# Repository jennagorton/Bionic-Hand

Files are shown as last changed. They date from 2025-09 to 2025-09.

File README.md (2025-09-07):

<h1 align="center">Bionic Hand</h1>
<p align="center">Jenna Gorton, July 2025</p>

<p align="center">
  workingTest
</p>
<p align="center">Opening and closing fist with button input</p>

About
==
In this project, I designed and built a bionic hand controlled by user input. I undertook this challenge to enhance my skills in CAD design, programming, and electronics. While only using my laptop, 3D printer, and Arduino, I was able to bring this idea to life. The primary goals were to achieve realistic hand motion and enable both independent and simultaneous control of individual fingers, while staying within a low budget.

<p align="center">
  workingTest
</p>

Design
==
The design incorporates compliant fingers, palm-integrated motors, a capacitive touch interface, and a cable-concealing stand.
- To introduce compliance in the fingers, I fabricated the joints using TPU, while the rest of the structure was printed in PLA. This material combination allowed the fingers to bend under applied force and return to their original position, providing the strength of a rigid finger with the flexibility of a compliant one.
- By integrating the servos within the palm, the hand functions independently without requiring an attached arm. This compact, self-contained design ensures compatibility with various arm attachments—whether used as a prosthetic or as a component of a larger robotic system.

Programming  
==

The bionic hand is controlled using an **Adafruit 16-Channel PWM Servo Driver** (PCA9685) and an Arduino. Each finger is assigned to a dedicated servo motor, which the driver addresses through I²C communication. The servos are configured with defined pulse-width ranges to open and close the fingers smoothly.  

### Key Features  
- **Finger Control**  
  The top row of capacitive touch sensors each corresponds to a specific finger. When touched, the associated servo toggles between open and closed positions, where the servo controls the closure, and the compliance pulls the finger open.

- **Predefined Gestures**  
  The second row of touch sensors allows for more complex motions:  
  - **Close Fist** – Sequentially closes all five fingers.  
  - **Open Hand** – Sequentially opens all five fingers.  
  - **Peace Sign** – Closes the thumb, ring, and pinky while opening the index and middle fingers.  

- **State Tracking**  
  Finger positions are tracked with global variables (`indexPos`, `thumbPos`, etc.) to prevent conflicting commands and allow toggling.  

- **Smooth Motion**  
  Servo positions are updated incrementally with small delays to create natural, fluid finger movements instead of abrupt snapping.  

### Example: Peace Sign Gesture  
Below is the function that creates a **peace sign** when the corresponding touch sensor is pressed:  

```cpp
if (c4r2 == 1) { // Peace sign gesture
  for (uint16_t pulselen = SERVOMAX, pulseopp = SERVOMIN; 
       pulselen > SERVOMIN && pulseopp < SERVOMAX; 
       pulselen--, pulseopp++) {
    // Closing thumb, ring, pinky
    if (thumbPos == 0) pwm.setPWM(THUMB, 0, pulselen);
    if (ringPos == 0)  pwm.setPWM(RING, 0, pulselen);
    if (pinkyPos == 0) pwm.setPWM(PINKY, 0, pulselen);

    // Opening index, middle
    if (middlePos == 1) pwm.setPWM(MIDDLE, 0, pulseopp);
    if (indexPos == 1)  pwm.setPWM(INDEX, 0, pulseopp);

    delay(3); // Smooth motion
  }
  indexPos = middlePos = 0; // Open
  ringPos = pinkyPos = thumbPos = 1; // Closed
}

```
Demo
==
The fingers can be configured to create any hand gesture 

| <div align="center">GIF 1<br></div> | <div align="center">GIF 2<br></div> |
|---|---|
| <div align="center">GIF 3<br></div> | <div align="center">GIF 4<br></div> |

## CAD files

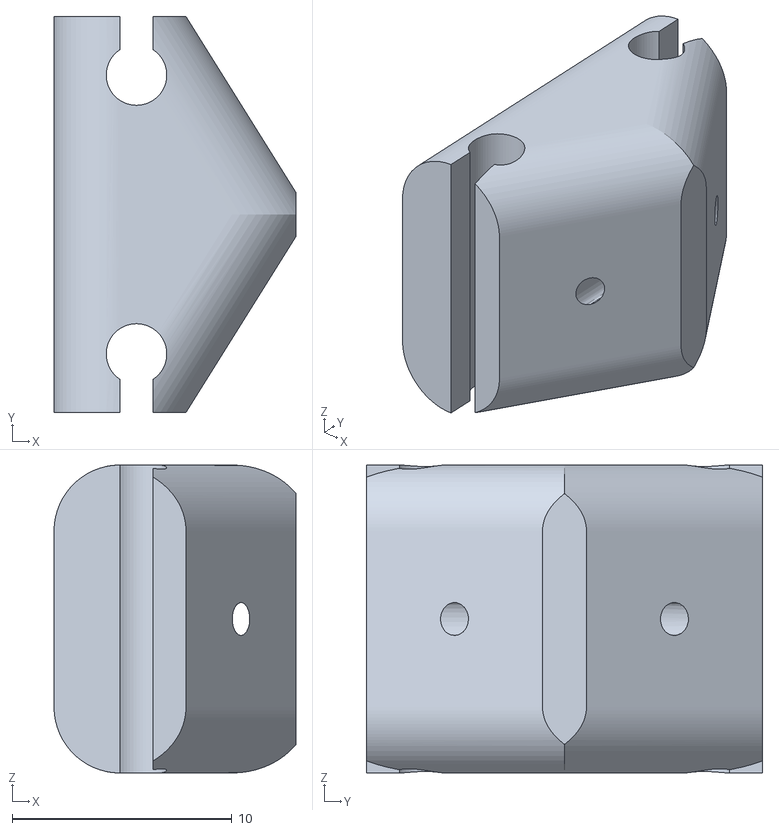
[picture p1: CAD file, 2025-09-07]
STL Files/Assembly 2 - P Middle.stl
11.0 x 18.0 x 14.0

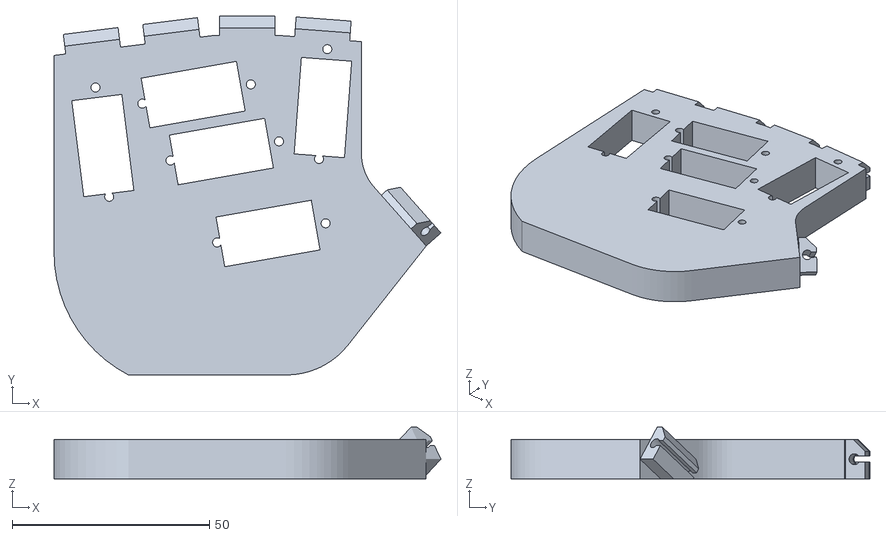
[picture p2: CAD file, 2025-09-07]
STL Files/Assembly 2 - Part 1.stl
98.2 x 91.1 x 13.1

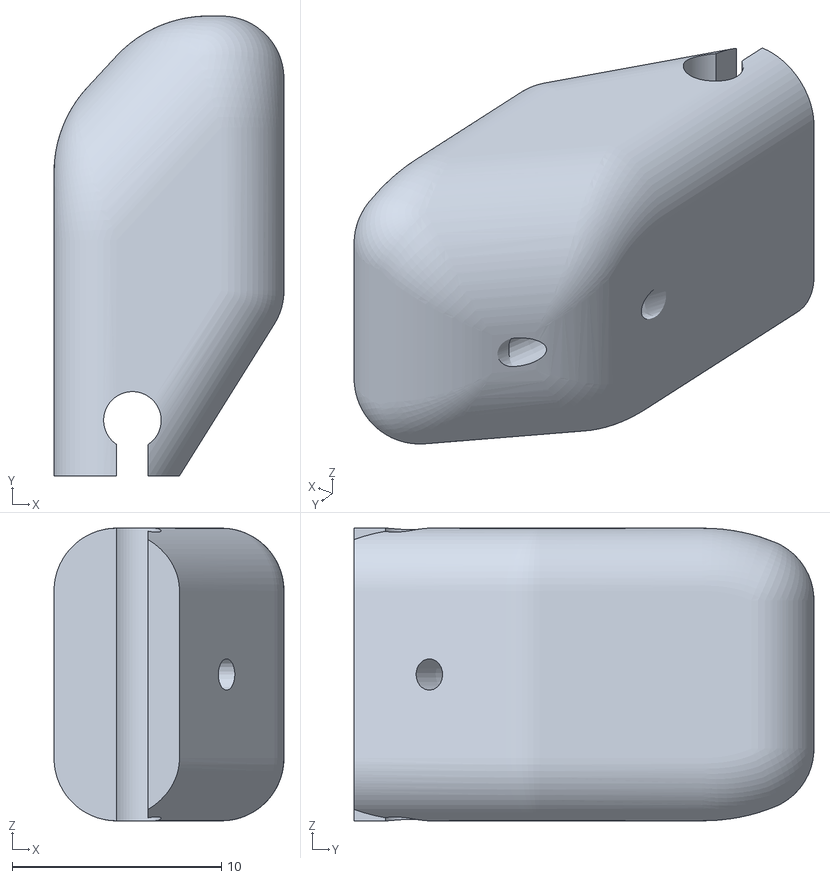
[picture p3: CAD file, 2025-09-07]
STL Files/Assembly 2 - P Tip.stl
11.0 x 22.0 x 14.0

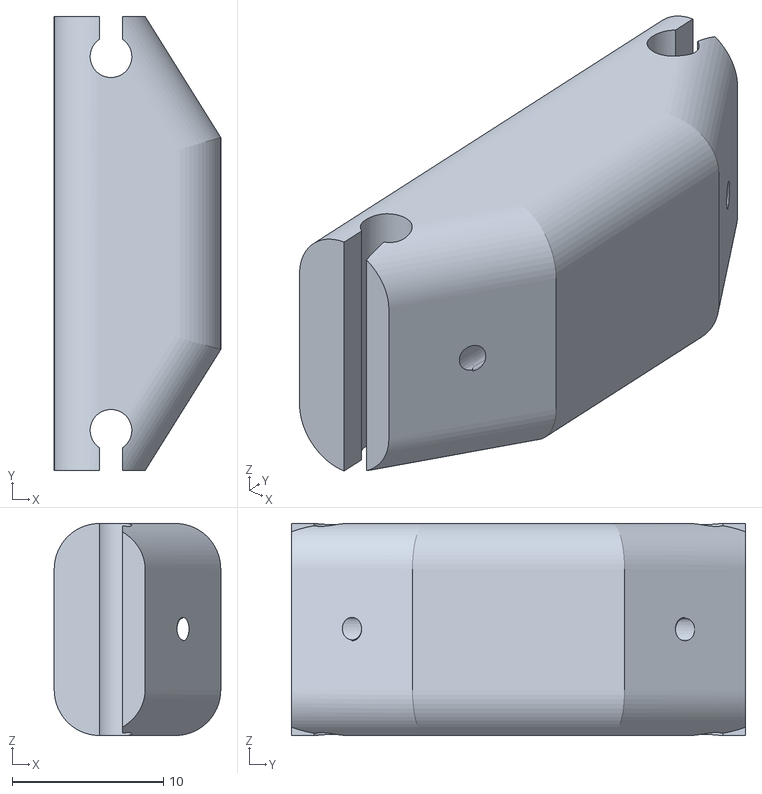
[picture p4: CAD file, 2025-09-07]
STL Files/Assembly 2 - M Base.stl
11.0 x 30.0 x 14.0

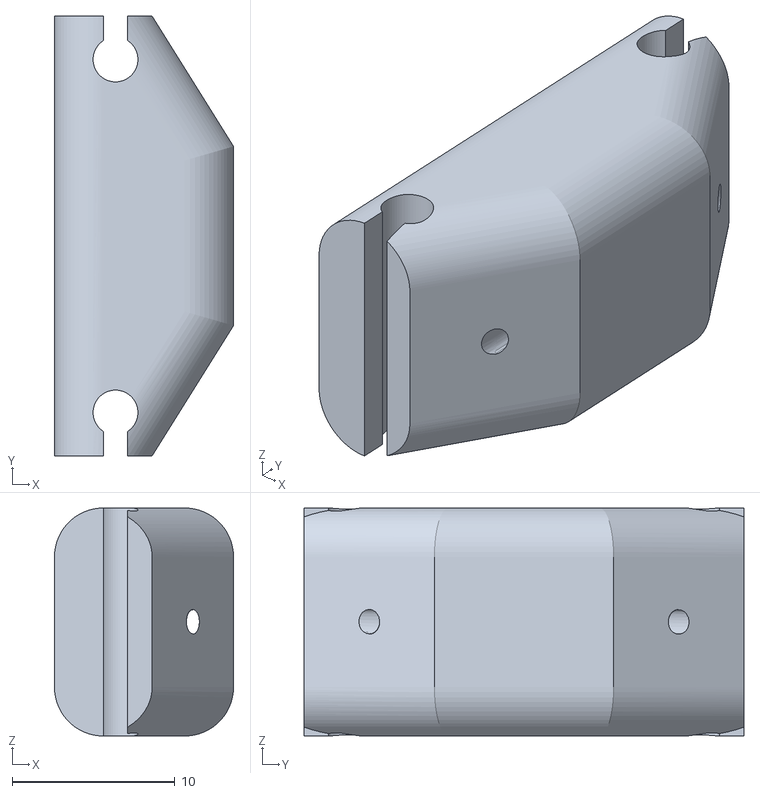
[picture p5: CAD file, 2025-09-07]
STL Files/Assembly 2 - IR Base.stl
11.0 x 27.0 x 14.0

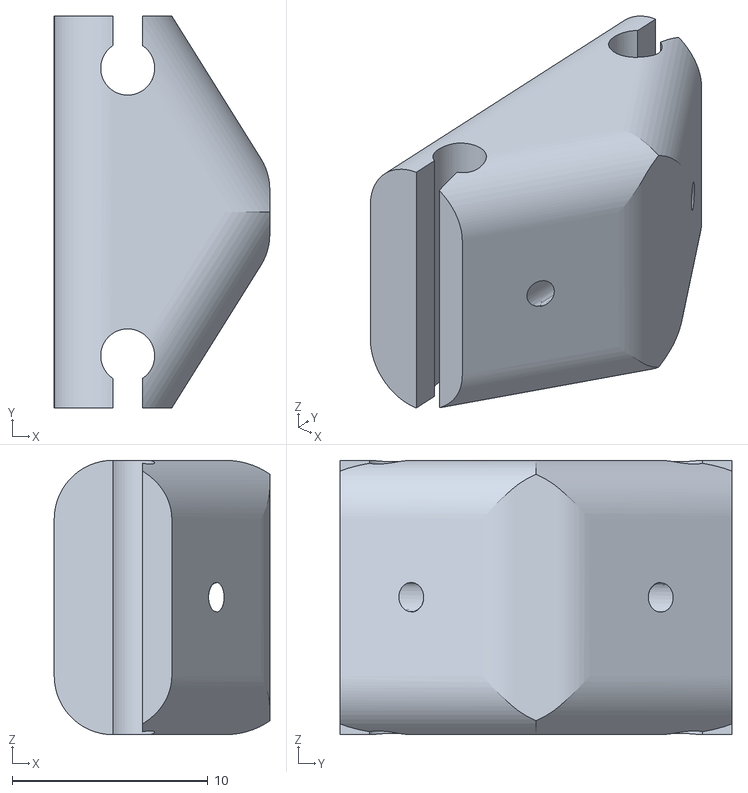
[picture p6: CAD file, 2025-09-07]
STL Files/Assembly 2 - IR Middle.stl
11.0 x 20.0 x 14.0

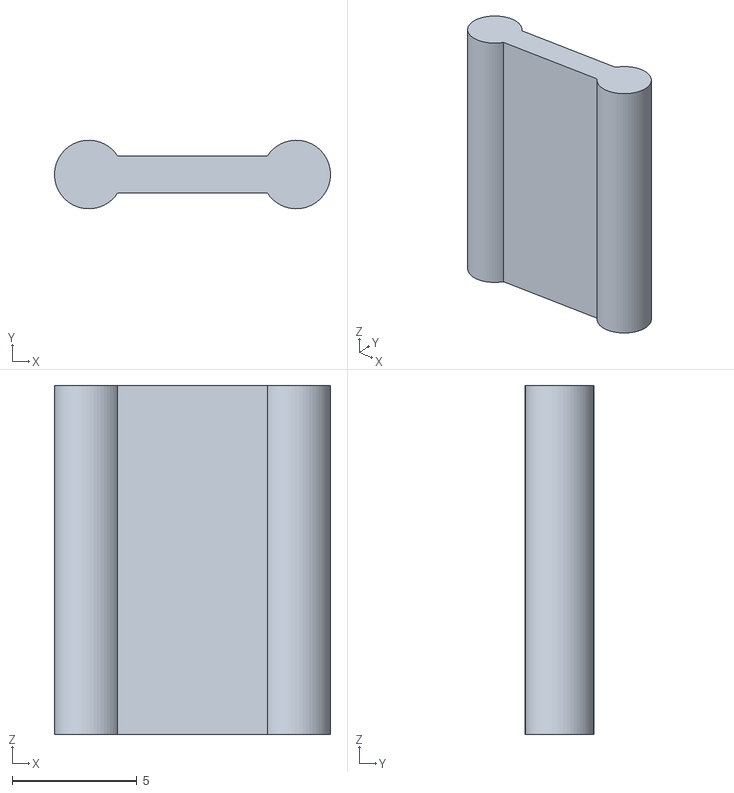
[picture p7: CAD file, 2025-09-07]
STL Files/Assembly 2 - Connector TPU.stl
11.1 x 2.75 x 14.0

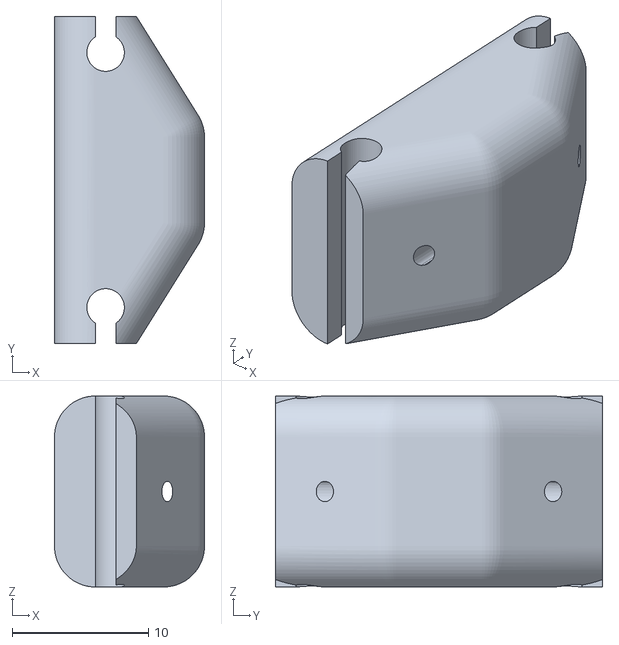
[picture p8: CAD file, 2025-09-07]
STL Files/Assembly 2 - M Middle.stl
11.0 x 24.0 x 14.0

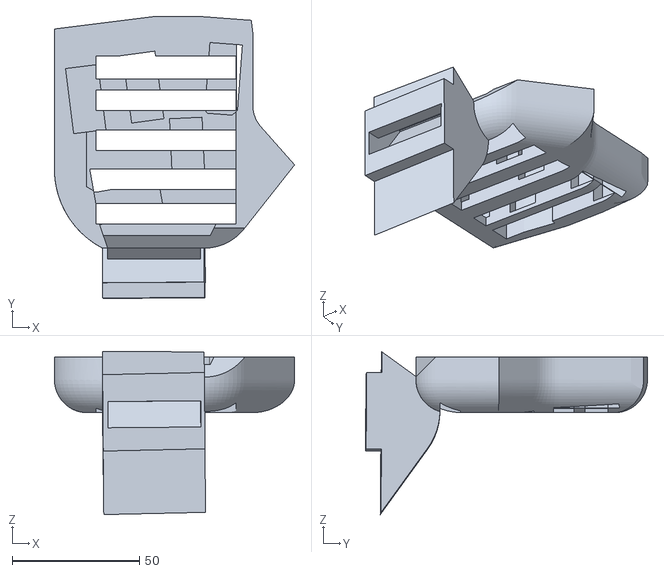
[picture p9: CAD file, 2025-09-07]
STL Files/Stand - Part 1.stl
94.4 x 110.8 x 64.1

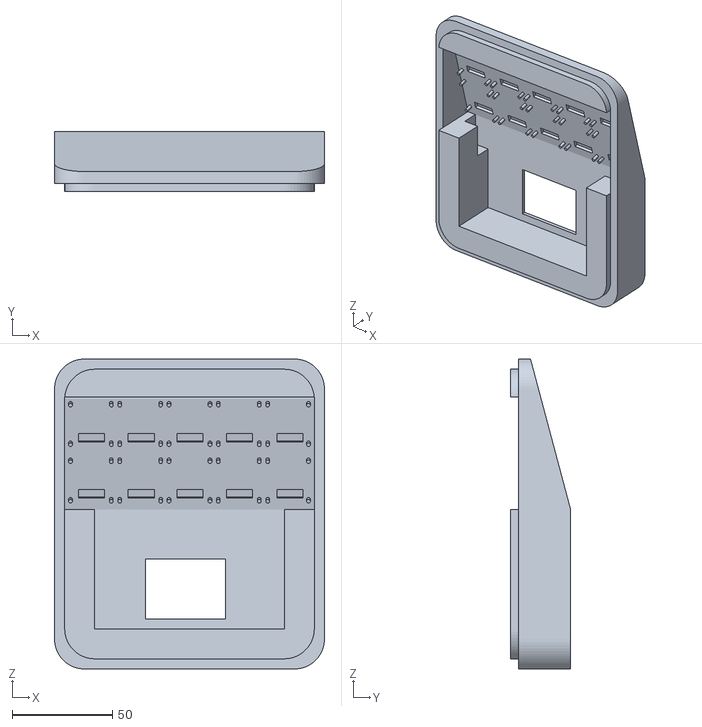
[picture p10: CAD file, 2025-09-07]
STL Files/Stand - Part 2.stl
135.0 x 30.0 x 155.0

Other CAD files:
STL Files/Assembly 2 - P Base.stl
STL Files/Assembly 2 - M Tip'.stl
STL Files/Assembly 2 - IR Tip.stl

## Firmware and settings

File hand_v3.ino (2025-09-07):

#include <Wire.h>
#include <Adafruit_PWMServoDriver.h>
Adafruit_PWMServoDriver pwm = Adafruit_PWMServoDriver(0x40);

#define SERVOMIN  125 // This is the 'minimum' pulse length count (out of 4096) 150
#define SERVOMAX  525 // This is the 'maximum' pulse length count (out of 4096) 550
#define SERVO_FREQ 50 // Analog servos run at ~50 Hz updates

//servo driver pin
#define MIDDLE 0
#define THUMB 1
#define RING 2
#define INDEX 3
#define PINKY 4



//global variable to track position 0:open 1:close
int indexPos = 0;
int middlePos = 0;
int thumbPos = 0;
int ringPos = 0;
int pinkyPos = 0;

void setup() {
  // put your setup code here, to run once:

  pinMode(6, INPUT);
  pinMode(5, INPUT);


  Serial.begin(9600);
  pwm.begin();
  pwm.setPWMFreq(50);

  //initalize all servos open
  pwm.setPWM(PINKY, 0, SERVOMAX);
  pwm.setPWM(RING, 0, SERVOMAX);
  pwm.setPWM(INDEX, 0, SERVOMAX);
  pwm.setPWM(MIDDLE, 0, SERVOMAX);
  pwm.setPWM(THUMB, 0, SERVOMAX);


  Serial.println("Type hand gesture");


}

void loop() {
  // Wait for user input
  while (!Serial.available()) {
    // do nothing until user types something

    //testing touch sensor
    int c1r1 = digitalRead(2);
    int c2r1 = digitalRead(3);
    //int c3r1 = digitalRead(4);
    int c4r1 = digitalRead(5);
    //int c5r1 = digitalRead(6);
    int c3r2 = digitalRead(7);
    int c2r2 = digitalRead(8);
    int c3r1 = digitalRead(9);
    int c4r2 = digitalRead(10);
    int c5r1 = digitalRead(11);
    delay(50);

    // Check each touch input
    //top row
    if (c1r1 == 1) Serial.println("c1r1 touched");
    if (c2r1 == 1) Serial.println("c2r1 touched");
    if (c3r1 == 1) Serial.println("c3r1 touched");
    if (c4r1 == 1) Serial.println("c4r1 touched");
    if (c4r2 == 1) Serial.println("c4r2 touched");
    
    //bottom row
    if (c2r2 == 1) Serial.println("c2r2 touched");
    if (c3r2 == 1) Serial.println("c3r2 touched");
    if (c5r1 == 1) Serial.println("c5r1 touched");
    
    String input = Serial.readStringUntil('\n');
    input.trim(); // remove any whitespace or newline characters

    /***************FIRST ROW SENSORS********************/
    //each sensor controls one finger to open and close
    if(c1r1 == 1 && pinkyPos != 1){
      pwm.setPWM(PINKY, 0, SERVOMIN);
      pinkyPos = 1;
    }
    else if(c1r1 == 1 && pinkyPos == 1){
      pwm.setPWM(PINKY, 0, SERVOMAX);
      pinkyPos = 0;
    }

    if(c2r1 == 1 && ringPos != 1){
      pwm.setPWM(RING, 0, SERVOMIN);
      ringPos = 1;
    }
    else if(c2r1 == 1 && ringPos == 1){
      pwm.setPWM(RING, 0, SERVOMAX);
      ringPos = 0;
    }

    if(c3r1 == 1 && middlePos != 1){
      pwm.setPWM(MIDDLE, 0, SERVOMIN);
      middlePos = 1;
    }
    else if(c3r1 == 1 && middlePos == 1){
      pwm.setPWM(MIDDLE, 0, SERVOMAX);
      middlePos = 0;
    }

    if(c4r1 == 1 && indexPos != 1){
      pwm.setPWM(INDEX, 0, SERVOMIN);
      indexPos = 1;
    }
    else if(c4r1 == 1 && indexPos == 1){
      pwm.setPWM(INDEX, 0, SERVOMAX);
      indexPos = 0;
    }

    if(c5r1 == 1 && thumbPos != 1){
      pwm.setPWM(THUMB, 0, SERVOMIN);
      thumbPos = 1;
    }
    else if(c5r1 == 1 && thumbPos == 1){
      pwm.setPWM(THUMB, 0, SERVOMAX);
      thumbPos = 0;
    }

    /***************SECOND ROW SENSORS********************/
    if (c2r2 == 1){ // close fist 
      for (uint16_t pulselen = SERVOMAX; pulselen > SERVOMIN; pulselen--) { //closing
        if (indexPos == 0){
          pwm.setPWM(INDEX, 0, pulselen);
        }
        if (middlePos == 0){
            pwm.setPWM(MIDDLE, 0, pulselen);
        }

        if (ringPos == 0){
            pwm.setPWM(RING, 0, pulselen);
        }

        if (pinkyPos == 0){
            pwm.setPWM(PINKY, 0, pulselen);
        }

        if (thumbPos == 0){
            pwm.setPWM(THUMB, 0, pulselen);
        }
        delay(3);
      }
      indexPos = middlePos = ringPos = pinkyPos = thumbPos = 1;
    }

    if (c3r2 == 1){ // open all
      for (uint16_t pulselen = SERVOMIN; pulselen < SERVOMAX; pulselen++) { //opening
        if (indexPos == 1){
            pwm.setPWM(INDEX, 0, pulselen);
        }
        
        if (middlePos == 1){
            pwm.setPWM(MIDDLE, 0, pulselen);
        }

        if (ringPos == 1){
            pwm.setPWM(RING, 0, pulselen);
        }

        if (pinkyPos == 1){
            pwm.setPWM(PINKY, 0, pulselen);
        }

        if (thumbPos == 1){
            pwm.setPWM(THUMB, 0, pulselen);
        }
        delay(3);
      }
      indexPos = middlePos = ringPos = pinkyPos = thumbPos = 0;
    }

    if (c4r2 == 1){ //peace sign
      for (uint16_t pulselen = SERVOMAX, pulseopp = SERVOMIN; 
        pulselen > SERVOMIN && pulseopp < SERVOMAX; 
        pulselen--, pulseopp++) {
        //closing
        if (thumbPos == 0) {
          pwm.setPWM(THUMB, 0, pulselen);
        }

        if (ringPos == 0) {
          pwm.setPWM(RING, 0, pulselen);
        }

        if (pinkyPos == 0) {
          pwm.setPWM(PINKY, 0, pulselen);
        }

        //opening
        if (middlePos == 1){
          pwm.setPWM(MIDDLE, 0, pulseopp);
        }
        
        if (indexPos == 1){
          pwm.setPWM(INDEX, 0, pulseopp);
        }
        delay(3);
      }
      indexPos = middlePos = 0;
      ringPos = pinkyPos = thumbPos = 1;
    }
  }
}
